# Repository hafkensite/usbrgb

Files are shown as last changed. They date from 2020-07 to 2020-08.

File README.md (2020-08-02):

# usbrgb

ATtiny85 based USB PCB that provides two WS2812B LED's, to be used as indicators.

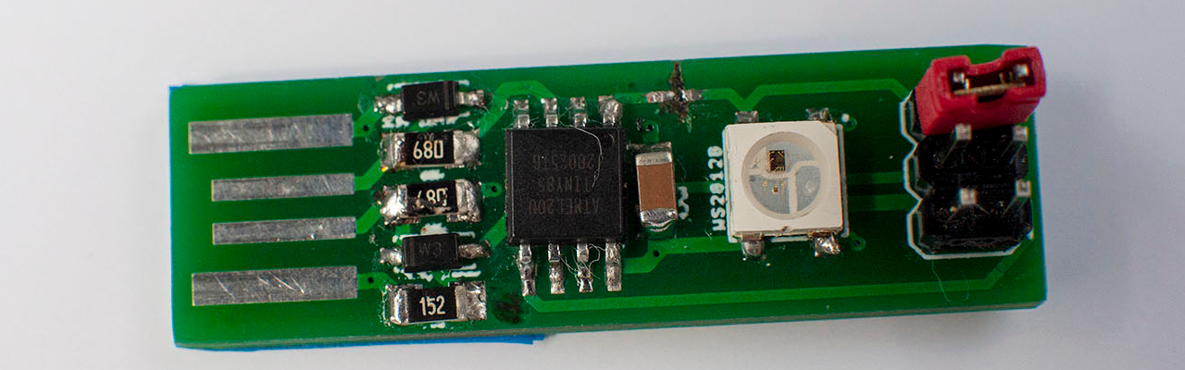
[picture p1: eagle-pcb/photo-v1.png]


# Hardware

The pcb design is based upon that of the [Digispark USB development board](http://digistump.com/products/1). For which they have released the [Eagle](https://s3.amazonaws.com/digistump-resources/files/3a5187f5_digispark_sources.zip) files.

The Digispark board uses an attiny84 microprocessor, which (with the help of some special software), can be programmed over USB once the bootloader is flashed once.

The width of the original Digispark pcb is slightly too wide to fit in some usb ports, when they are located at an edge. A fairly large part of the pcb is occupied by a voltage regulator. As the usbrgb PCB is to be used in a computer, there is no need for a 5Volt regulator.

Removing the regulator, and a few other non-critical components allowed the board to be narrower. I chose for a 'bigger' package for the passive components, as I want to solder it to manually.

## Layout

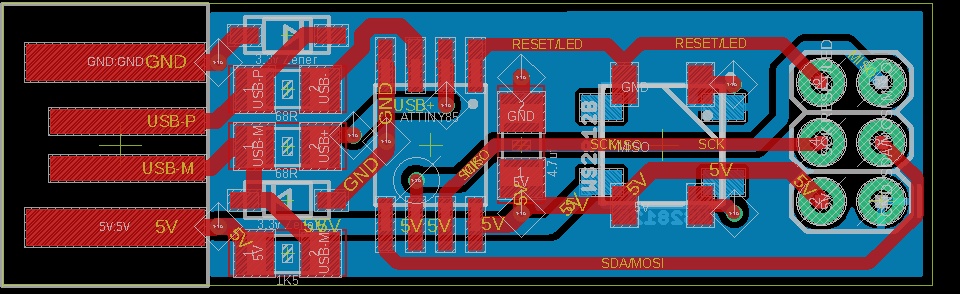
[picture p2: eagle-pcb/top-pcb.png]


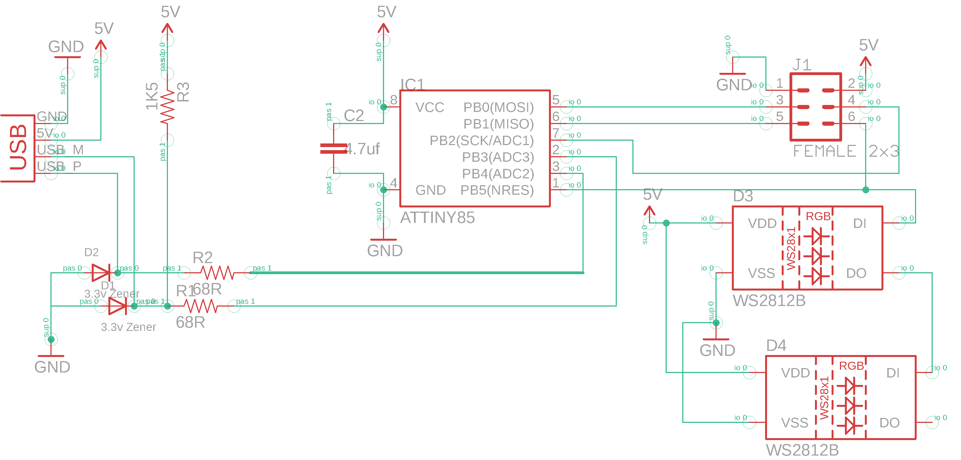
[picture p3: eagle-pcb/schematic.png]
Schematic


## Components

| Qty | Value | Package | Parts  | Description |
| --- | --- | --- | --- | --- |
| 1 | ATTINY85 | SOP8 | IC1 | Atmel ATTINY85-20SU |
| 2 | 68R | 1206 | R1, R2 | Resistor |
| 1 | 1K5 | 1206 | R3 | Resistor |
| 2 | 3.3v Zener | SOD-123 | D1, D2 | Diode |
| 1 | 4.7uf | C1206 | C2 | Capacitor |
| 2 | WS2812B | WS2812B | D3, D4 | WS2812B SMD addressable RGB LED |

# Embedded software

## Micronucleus bootloader
The [micronucleus](https://github.com/micronucleus/micronucleus) bootloader allows the Arduino IDE to program the chip over USB.

When the chip boots, it first presents itself as a usb device that can be programmed. After a short timeout the bootloader starts the Arduino code.

To flash the micronucleus bootloader you can use [avrdude](https://www.nongnu.org/avrdude/). I have programmed mine using an Arduino uno with the ISP sketch written to it.

## Arduino

To program the device using Arduino you can follow the steps describe in the [tutorial](http://digistump.com/wiki/digispark/tutorials/connecting).

> Note that the latest micronucleus version currently available (v2.04) is not supported by the Arduino plugin. I replaced the micronucleus application with the [latest version](https://github.com/micronucleus/micronucleus/tree/master/commandline), which works fine.

# Host software

The host application is written in Go, and uses the libusb interface to send control messages to the HID device. 

## Native messaging
The goal of this project is to be able to give a notification from within a browser. One of the ways to communicate from a browser to the host is using [native messaging](https://developer.mozilla.org/en-US/docs/Mozilla/Add-ons/WebExtensions/Native_messaging). This allows extensions to send messages to an executable on the host.

## Browser integration
The included firefox extension, together with the native-messaging application, allows the LED's to be set from within a web-page.

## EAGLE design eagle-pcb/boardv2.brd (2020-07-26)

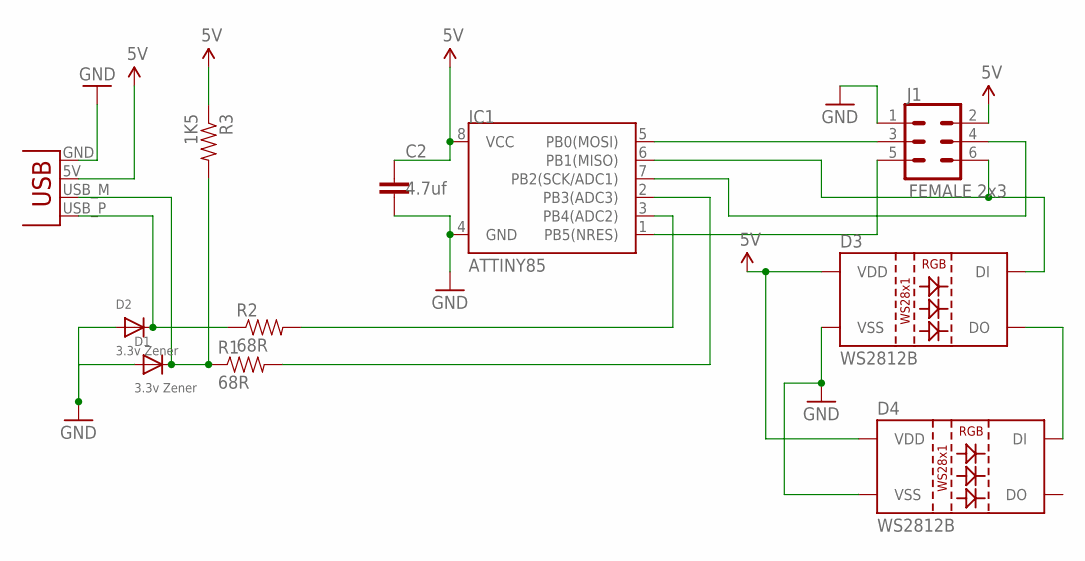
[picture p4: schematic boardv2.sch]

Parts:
C2: 4.7uf; C1206
D1, D2: 3.3v Zener; SOD-123
D3, D4: WS2812B
IC1: ATTINY85; SO08-EIAJ
J1: FEMALE 2x3; 2X3
R1, R2: 68R; 1206
R3: 1K5; 1206
X1: USBPCB; USB-A-PCB

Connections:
5V: C2.1, D3.1 (VDD), D4.1 (VDD), IC1.8 (VCC), J1.2, R3.1, X1.5V (VBUS)
GND: C2.2, D1.A, D2.A, D3.3 (VSS), D4.3 (VSS), IC1.4 (GND), J1.1, X1.GND
MISO: D3.4 (DI), IC1.6 (PB1(MISO)), J1.6
unnamed: D3.2 (DO), D4.4 (DI)
RESET: IC1.1 (PB5(NRES)), J1.5
SCK: IC1.7 (PB2(SCK/ADC1)), J1.4
SDA/MOSI: IC1.5 (PB0(MOSI)), J1.3
USB+: IC1.2 (PB3(ADC3)), R1.2
USB-: IC1.3 (PB4(ADC2)), R2.2
USB-M: D1.C, R1.1, R3.2, X1.USB_M (D-)
USB-P: D2.C, R2.1, X1.USB_P (D+)

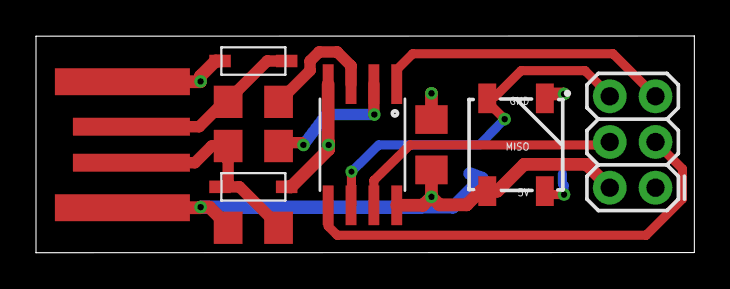
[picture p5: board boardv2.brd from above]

Board: 2 copper layers, 36.6 x 12.0 mm, 11 parts (1 on the bottom side), 11 nets.

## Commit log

2020-07-26 Added eagle pcb files v1
    [boardv2.brd, boardv2.sch]
2020-07-26 Added arduino code for serial emulator
2020-07-26 FIX pcb, use MOSI to drive LED, not RESET
    [boardv2.brd, boardv2.sch]

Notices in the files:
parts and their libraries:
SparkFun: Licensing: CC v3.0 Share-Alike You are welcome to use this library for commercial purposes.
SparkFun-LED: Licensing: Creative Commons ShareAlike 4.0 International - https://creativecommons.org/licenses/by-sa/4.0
